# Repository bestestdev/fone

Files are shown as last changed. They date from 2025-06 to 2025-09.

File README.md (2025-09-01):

# fone

A modern take on the classic Nokia cell phone experience, built with a Raspberry Pi Pico 2 running MicroPython. This project combines the simplicity and reliability of old-school Nokia phones with quality-of-life improvements for modern usability.

## Overview

**fone** is a DIY cellular phone that captures the essence of classic Nokia devices while incorporating modern components and conveniences. The device features a minimalist design focused on essential communication functions: calls, SMS, and basic navigation, all powered by MicroPython for easy customization and development.

## Hardware Components

### Core Processing
- **Raspberry Pi Pico 2** - Main microcontroller running MicroPython
- **W25Q128 SPI Flash** - 16MB flash storage for contacts, messages, and system data

### Cellular Communication
- **SIM7600G Module** - 4G/LTE cellular connectivity with GPS
- Connected via UART (TX/RX) to Pico 2

### Power Management
- **3700mAh Lithium Battery** - Long-lasting power source
- **TP4056 Charging Module** - Safe battery charging via USB-C
- **MT3608 Boost Converter** - Boost LiPo battery to 5v for use by the SIM module and Pico

### Audio System
- **MAX98357A I2S Amplifier** - Digital audio amplification
- **1W 8Ω Speaker** - Clear audio output for calls and notifications
- **GY-MAX4466 Electret Microphone** - Voice input with AGC
- **ADS1115 ADC** - High-resolution analog-to-digital conversion for microphone

### Display & Input
- **2.42" OLED Display (SSD1309)** - monochrome, 128x64 resolution, SPI interface, low power consumption
- **ANO Directional Navigation and Scroll Wheel Rotary Encoder** - Navigation, selection, scroll, and menu control
- **3V Coin Vibration Motor** - Haptic feedback and notifications

## Features

### Core Functionality
- **Voice Calls** - Make and receive phone calls with clear audio
- **SMS Messaging** - Send and receive text messages
- **Contact Management** - Store and organize phone contacts
- **Call History** - Track incoming, outgoing, and missed calls

### Enhanced User Experience
- **Improved Text Input** - Modern T9-style predictive text with encoder navigation
- **Menu Navigation** - Intuitive interface designed for encoder and directional button control
- **Scroll Wheel Support** - Rotary encoder provides smooth scrolling through lists and menus
- **Low Power Operation** - E-paper display and efficient power management
- **Haptic Feedback** - Vibration for notifications and user interactions

### Additional Features
- **GPS Location (Stretch Goal)** - Built-in positioning via SIM7600G
- **Battery Monitoring** - Real-time battery level and charging status
- **Silent/Vibrate Modes** - Customizable notification preferences
- **Basic Games** - Classic Nokia-style entertainment (Snake, etc.)

## Technical Specifications

### Connectivity
- **Cellular**: 4G LTE via SIM7600G
- **GPS (Stretch Goal)**: Built-in GNSS receiver
- **Storage**: 16MB SPI flash memory (W25Q128)

### Power
- **Battery Life**: All-day usage with 3700mAh capacity
- **Charging**: USB charging via TP4056 module
- **Standby**: Ultra-low power consumption with e-paper display

### Interface
- **Display**: 2.42" monochrome OLED (128x64px)
- **Input**: ANO rotary encoder with directional navigation buttons
- **Audio**: Full-duplex voice communication
- **Feedback**: Vibration motor for alerts

## Software Architecture

- **Platform**: MicroPython on Raspberry Pi Pico 2
- **Modular Design**: Separate modules for cellular, audio, display, and input handling
- **Event-Driven**: Efficient power management through interrupt-based operation
- **Extensible**: Easy to add new features and customize behavior

## Wiring Guide

### SIM7600G to Raspberry Pi Pico 2

The SIM7600G module connects via UART and requires the following connections:

| SIM7600G Pin | Description | Connection | Notes |
|---|---|---|---|
| **V** | VCC | **5V from MT3608** | Requires stable 5V (up to 2A) |
| **G** | Ground | **Battery -** | Battery ground |
| **G** | Ground | **Pico GND** (Pin 38) | Shared ground with Pico |
| **T** | TX (Module transmit) | **GP1** (Pin 2) | UART0 RX |
| **R** | RX (Module receive) | **GP0** (Pin 1) | UART0 TX |
| **K** | Power Key | **GP2** (Pin 4) | GPIO for power control |
| **S** | Status | **GP3** (Pin 5) | GPIO for status monitoring |

#### Key Points:
- **Power**: SIM7600G requires 5V via MT3608 boost converter for proper RF operation
- **Current Draw**: Module can draw up to 2A during transmission bursts
- **UART**: Cross-connect TX/RX (module TX → Pico RX, module RX → Pico TX)
- **Power Key**: Pull HIGH briefly to turn module on/off
- **Status**: Monitor this pin to check if module is powered and ready
- **Dual Ground**: Connect both ground pins for stable operation

### ANO Directional Navigation and Scroll Wheel Rotary Encoder

The primary input is an ANO directional navigation and scroll wheel rotary encoder, providing directional control, rotary scroll input, and a center-press button.

| Encoder Pin | Description | Connection | Notes |
|---|---|---|---|
| **ENCA** | Encoder A Pin | **GP17** (Pin 22) | Rotary encoder quadrature A |
| **ENCB** | Encoder B Pin | **GP22** (Pin 29) | Rotary encoder quadrature B |
| **SW1** | Center Button | **GP6** (Pin 9) | Digital input |
| **SW2** | Down Button | **GP5** (Pin 7) | Digital input |
| **SW3** | Right Button | **GP4** (Pin 6) | Digital input |
| **SW4** | Up Button | **GP19** (Pin 25) | Digital input |
| **SW5** | Left Button | **GP18** (Pin 24) | Digital input |
| **COM** | Common | **GND** (Pin 38) | Common ground for all switches |

#### Key Points:
- **Rotary Encoder**: ENCA/ENCB provide quadrature signals for scroll wheel functionality
- **Digital Buttons**: All switch pins (SW1-SW5) are simple digital inputs
- **Wiring**: Connect the COM pin to GND and configure each GPIO pin as an input with an internal pull-up resistor
- **Active Low**: Button presses and encoder transitions pull pins to ground (LOW)
- **Quadrature Decoding**: Software tracks encoder A/B state changes to determine rotation direction and steps

### Dual Analog Joysticks via ADS1115 ADC

> **Note:** This component has been deprecated and replaced by the ANO Directional Navigation and Scroll Wheel Rotary Encoder.

The phone uses two analog joysticks for navigation and input, connected through an ADS1115 16-bit ADC for full 4-channel analog precision.

**ADS1115 ADC Module:**

| ADS1115 Pin | Description | Connection | Notes |
|---|---|---|---|
| **VDD** | Power | **5V** (Pin 40 - VBUS) | Module power supply |
| **GND** | Ground | **GND** (Pin 38) | Common ground |
| **SCL** | I2C Clock | **GP21** (Pin 27) | I2C0 SCL |
| **SDA** | I2C Data | **GP20** (Pin 26) | I2C0 SDA |
| **ADDR** | Address | **GND** | Sets I2C address to 0x48 |

**Left Joystick (mounted upside down):**

| Joystick Pin | Description | Connection | Notes |
|---|---|---|---|
| **VCC** | Power | **5V** (Pin 40 - VBUS) | Joystick power supply |
| **GND** | Ground | **GND** (Pin 38) | Common ground |
| **VRX** | X-axis analog | **ADS1115 AIN0** | Left joystick X |
| **VRY** | Y-axis analog | **ADS1115 AIN1** | Left joystick Y (inverted) |
| **SW** | Switch button | **GP19** (Pin 25) | Digital input with pull-up |

**Right Joystick:**

| Joystick Pin | Description | Connection | Notes |
|---|---|---|---|
| **VCC** | Power | **5V** (Pin 40 - VBUS) | Joystick power supply |
| **GND** | Ground | **GND** (Pin 38) | Common ground |
| **VRX** | X-axis analog | **ADS1115 AIN2** | Right joystick X |
| **VRY** | Y-axis analog | **ADS1115 AIN3** | Right joystick Y |
| **SW** | Switch button | **GP18** (Pin 24) | Digital input with pull-up |

#### Key Points:
- **Full Analog Control**: ADS1115 provides 4 channels of 16-bit ADC precision
- **I2C Address**: 0x48 (ADDR pin to GND), can be changed for multiple modules
- **Left Joystick**: Mounted upside down, so Y-axis values are inverted in software
- **ADC Resolution**: 16-bit (±32767) with ±4.096V input range matches 5V joysticks
- **Switches**: Active low with internal pull-up resistors on Pico pins (3.3V logic)
- **Update Rate**: ~128 SPS (samples per second) for smooth control

### 3V Vibration Motor

The vibration motor provides haptic feedback for notifications and user interactions.

#### Option 1: Direct GPIO Control (Recommended to try first)

**For Low Current Motors (< 40mA):**

| Motor Pin | Description | Connection | Notes |
|---|---|---|---|
| **+** | Positive | **GP16** (Pin 21) | Direct PWM control |
| **-** | Negative | **GND** (Pin 38) | Direct ground connection |

#### Option 2: Transistor-Protected Control

**For Higher Current Motors (> 40mA) or if direct control fails:**

| Motor Pin | Description | Connection | Notes |
|---|---|---|---|
| **+** | Positive | **GP16** (Pin 21) via NPN Transistor | PWM-controlled output |
| **-** | Negative | **GND** (Pin 38) | Direct ground connection |

**Transistor Circuit (NPN - 2N2222 or similar):**

| Transistor Pin | Description | Connection | Notes |
|---|---|---|---|
| **Base** | Control | **GP16** (Pin 21) via 1kΩ resistor | PWM signal from Pico |
| **Collector** | High side | **Motor +** | Connects to motor positive |
| **Emitter** | Ground | **GND** (Pin 38) | Common ground |

#### Key Points:
- **Motor Specs**: 3V, 12000 RPM, small coin-type vibration motor
- **Current Draw**: Small motors (17-35mA) can connect directly, larger motors (60-105mA) need transistor
- **Pico GPIO Limits**: ~16mA safe, ~50mA maximum per pin
- **Try Direct First**: Start with Option 1 - if motor doesn't work well or Pico gets warm, use Option 2
- **Flyback Diode**: Optional 1N4001 diode across motor (cathode to +, anode to -) for back-EMF protection
- **Control**: PWM control via GP16 allows variable vibration intensity
- **Frequency**: Typical vibration patterns: short bursts (100-300ms) for notifications

### 2.42" OLED Display (SSD1309)

The 2.42" monochrome OLED display provides the main user interface with a 128x64 resolution using SPI communication.

**Display Module Connections:**

| Display Pin | Description | Connection | Notes |
|---|---|---|---|
| **VCC** | Power | **3V3** (Pin 36) | 3.3V power supply |
| **GND** | Ground | **GND** (Pin 38) | Common ground |
| **CLK** | SPI Clock | **GP10** (Pin 14) | SPI1 SCK |
| **DIN** | SPI Data In | **GP11** (Pin 15) | SPI1 MOSI (TX) |
| **CS** | Chip Select | **GP9** (Pin 12) | SPI chip select (active low) |
| **DC** | Data/Command | **GP12** (Pin 16) | Command mode control |
| **RST** | Reset | **GP13** (Pin 17) | Hardware reset (active low) |

#### Key Points:
- **SPI Interface**: Uses SPI1 on Pico 2 for communication
- **Monochrome Display**: Black and white output with high contrast
- **Resolution**: 128x64 pixels provides clear text and simple graphics
- **Fast Updates**: ~10ms refresh time for full screen updates
- **Low Power**: Efficient power consumption (perfect for phone standby)
- **Rotation Support**: Software rotation for portrait or landscape orientation
- **Viewing Angle**: Wide viewing angle (>160°) for clear visibility
- **Compact Size**: 2.42" diagonal with minimal bezel

### W25Q128 SPI Flash Memory Module

The W25Q128 provides 16MB (128Mbit) of non-volatile storage for contacts, messages, and system data, connected via SPI interface. This flash memory offers faster access times and lower power consumption compared to SD cards.

**W25Q128 Module Connections:**

| W25Q128 Pin | Description | Connection | Notes |
|---|---|---|---|
| **VCC** | Power | **3V3** (Pin 36) | 3.3V power supply |
| **GND** | Ground | **GND** (Pin 38) | Common ground |
| **DC** | SPI Data Out (MISO) | **GP8** (Pin 11) | SPI1 MISO (RX) |
| **D1** | SPI Data In (MOSI) | **GP11** (Pin 15) | SPI1 MOSI (TX) - **Shared with display** |
| **SLK** | SPI Clock | **GP10** (Pin 14) | SPI1 SCK - **Shared with display** |
| **CS** | Chip Select | **GP7** (Pin 10) | SPI chip select (active low) |

#### Key Points:
- **Shared SPI Bus**: Uses SPI1 shared with the e-paper display (SLK, D0 pins)
- **Separate MISO**: Flash memory has its own MISO line (D1/GP8) since display is write-only
- **Unique CS**: Each device has its own chip select (Flash: GP7, Display: GP9)
- **Power**: 3.3V operation, low power consumption (4mA active, <1µA standby)
- **Storage**: 16MB of flash memory with 100,000+ erase/program cycles
- **Performance**: Up to 104MHz SPI clock, much faster than SD card access
- **File System**: Can use LittleFS or FAT filesystem via MicroPython's VFS

### MAX98357A I2S Amplifier and Speaker

The MAX98357A is a digital I2S audio amplifier used to drive the speaker for calls, notifications, and other audio feedback.

**MAX98357A Module Connections:**

| MAX98357A Pin | Description | Connection | Notes |
|---|---|---|---|
| **Vin** | Power In | **5V** (Pin 40 - VBUS) | 3-5.5V input range |
| **GND** | Ground | **GND** (Pin 38) | Common ground |
| **DIN** | Data In | **GP20** (Pin 26) | I2S Serial Data |
| **BCLK** | Bit Clock | **GP14** (Pin 19) | I2S Bit Clock |
| **LRC** | Left-Right Clock | **GP15** (Pin 20) | I2S Word Select |
| **SD** | Shutdown | **GP21** (Pin 27) | Active-low shutdown control |
| **GAIN** | Gain Select | *(unconnected)* | Default 9dB gain. Connect to GND for 3dB, VCC for 15dB. |

**Speaker Connection:**

| Component | Connection |
|---|---|
| **Speaker +** | **MAX98357A Left/Right +** |
| **Speaker -** | **MAX98357A Left/Right -** |

#### Key Points:
- **I2S Audio**: Digital audio provides clear, noise-free sound.
- **Power**: Connected to 5V for maximum speaker volume.
- **Shutdown Pin**: GP21 controls the amplifier's shutdown mode to conserve power.
- **Mono Output**: Although the module has L/R outputs, it's a mono amplifier. Connect speaker to either pair.
- **Gain Control**: The `GAIN` pin can be used to adjust the amplification level if needed. Default (unconnected) is 9dB.

### GY-MAX4466 Electret Microphone

The GY-MAX4466 microphone module with automatic gain control (AGC) is used for voice input. It's connected directly to one of the Pico's ADC pins.

**Microphone Module Connections:**

| Microphone Pin | Description | Connection | Notes |
|---|---|---|---|
| **VCC** | Power | **3V3** (Pin 36) | 2.4-5.5V input range |
| **GND** | Ground | **GND** (Pin 38) | Common ground |
| **OUT** | Analog Out | **GP28** (Pin 34) | Connects to ADC2 |

#### Key Points:
- **Direct ADC Connection**: Simplifies wiring and reduces component count.
- **Analog Pin**: Uses `GP28`, one of the Pico's three dedicated ADC pins.
- **Power**: Runs on 3.3V power provided by the Pico.
- **AGC**: The MAX4466's automatic gain control adjusts for varying sound levels.

### Battery Level Monitoring

To monitor the battery level, a voltage divider is used to scale the battery's voltage (3.0V-4.2V) down to a range the Pico's ADC can safely read (0-3.3V). The reading is taken on the now-available ADC pin.

**Voltage Divider Circuit:**

| Component | Connection | Notes |
|---|---|---|
| **Battery +** | Resistor 1 (R1) - e.g., 100kΩ | Connects to the positive battery terminal |
| **R1 + R2** | **GP26** (Pin 31) & Resistor 2 (R2) | Center point connects to Pico's ADC pin |
| **R2** | **GND** (Pin 38) | Connects to ground |

*A 1:1 ratio (e.g., two 100kΩ resistors) is simple and effective.*

**Pin Connection:**

| Description | Connection | Notes |
|---|---|---|
| **Voltage Sense** | **GP26** (Pin 31) | ADC capable pin (ADC0) |

#### Key Points:
- **Voltage Divider**: Essential to prevent damage to the Pico's ADC.
- **Resistor Choice**: Using identical resistors (e.g., 100kΩ) creates a simple 1:2 divider. The actual voltage is `2 * adc_voltage`.
- **ADC Reading**: The software must read the analog value from `GP26` and multiply it by the divider ratio to calculate the true battery voltage.

*[Development in progress - setup instructions coming soon]*

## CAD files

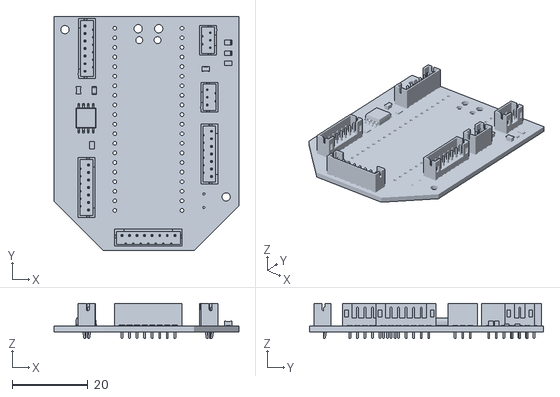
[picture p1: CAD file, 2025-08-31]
stls/fone-pcb.stl
49.0 x 62.0 x 9.40

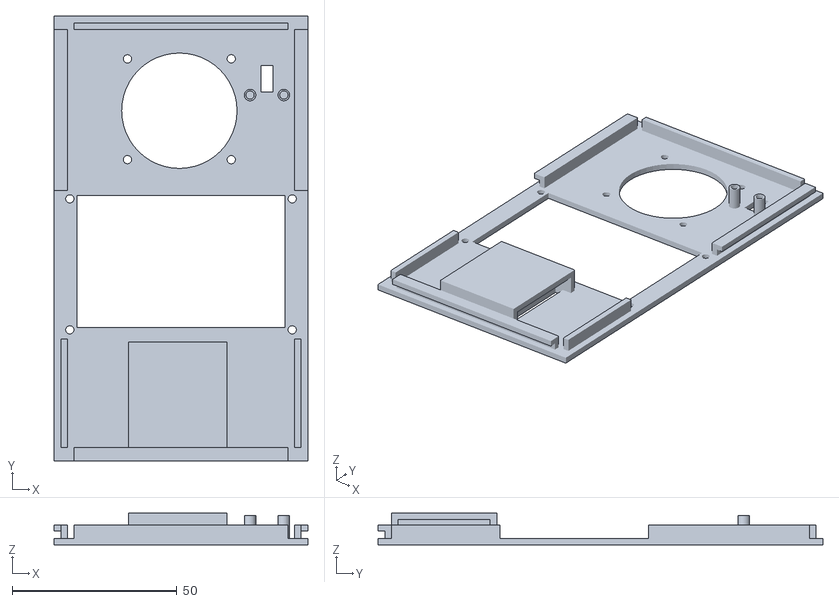
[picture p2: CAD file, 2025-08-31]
stls/fone 0.5 top.stl
77.0 x 135.1 x 9.70

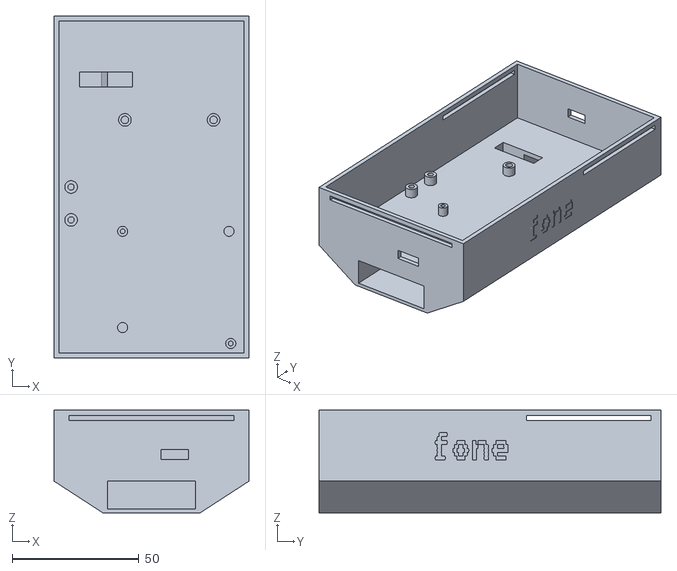
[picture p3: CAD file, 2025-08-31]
stls/fone 0.5 bottom.stl
77.0 x 135.0 x 40.5

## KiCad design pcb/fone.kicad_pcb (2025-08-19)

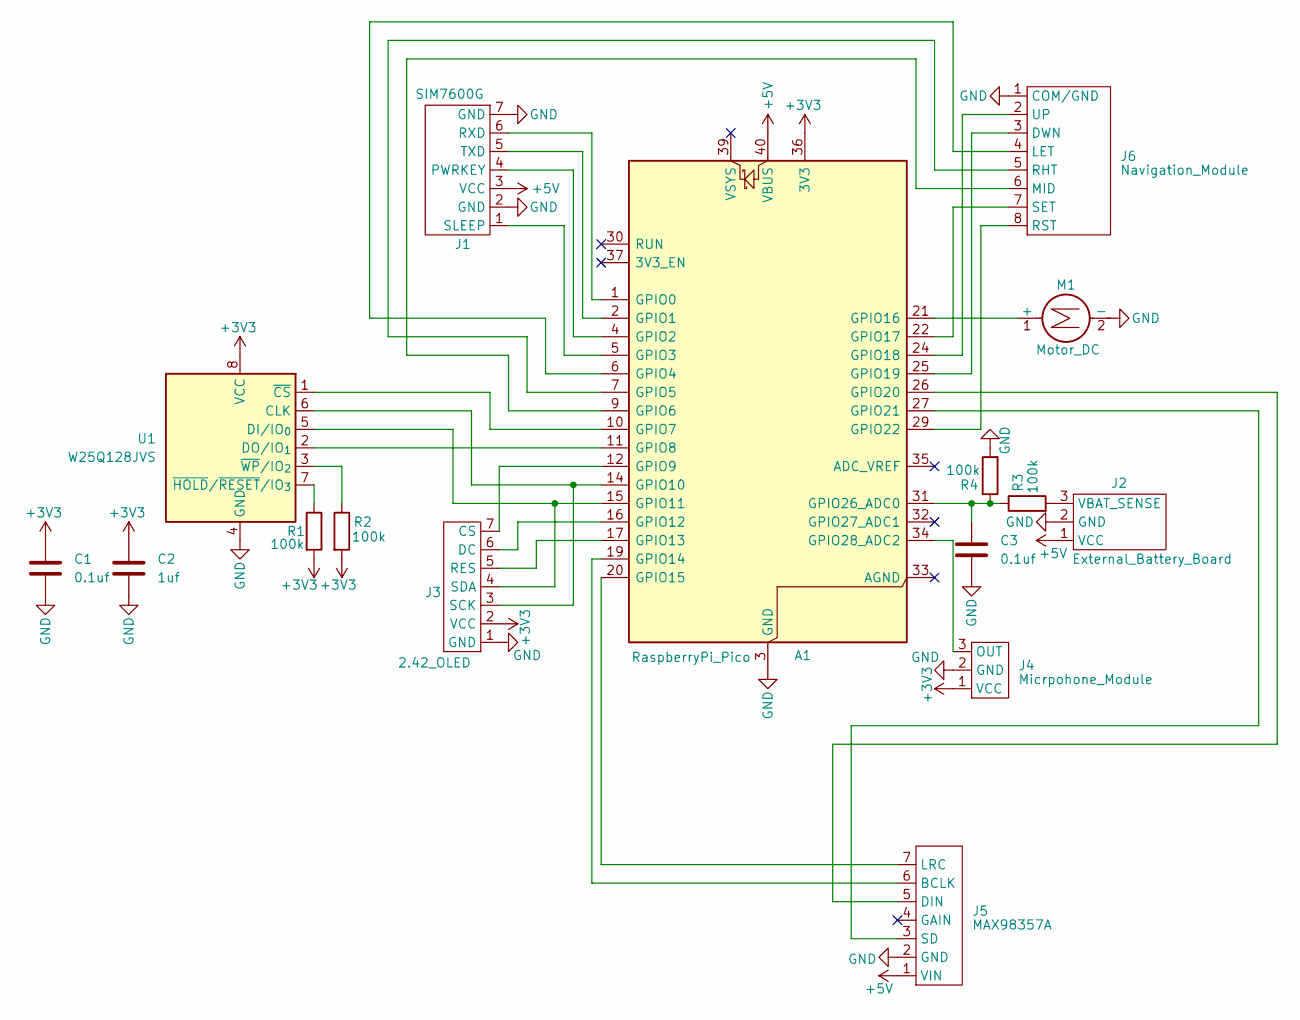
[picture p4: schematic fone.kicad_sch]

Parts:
A1: RaspberryPi_Pico; RaspberryPi_Pico_Common_Unspecified
C1, C3: 0.1uf; C_0805_2012Metric_Pad1.18x1.45mm_HandSolder
C2: 1uf; C_0805_2012Metric_Pad1.18x1.45mm_HandSolder
J1: SIM7600G; JST_PH_B7B-PH-K_1x07_P2.00mm_Vertical
J2: External_Battery_Board; JST_PH_B3B-PH-K_1x03_P2.00mm_Vertical
J3: 2.42_OLED; JST_PH_B7B-PH-K_1x07_P2.00mm_Vertical
J4: Micrpohone_Module; JST_PH_B3B-PH-K_1x03_P2.00mm_Vertical
J5: MAX98357A; JST_PH_B7B-PH-K_1x07_P2.00mm_Vertical
J6: Navigation_Module; JST_PH_B8B-PH-K_1x08_P2.00mm_Vertical
M1: Motor_DC; SolderWire-2sqmm_1x02_P7.8mm_D2mm_OD3.9mm
R1, R2, R3, R4: 100k; R_0805_2012Metric_Pad1.20x1.40mm_HandSolder
U1: W25Q128JVS; SOIC-8_5.3x5.3mm_P1.27mm

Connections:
+3V3: A1.36 (3V3), C1.1, C2.1, J3.2 (VCC), J4.1 (VCC), R1.2, R2.2, U1.8 (VCC)
+5V: A1.40 (VBUS), J1.3 (VCC), J2.1 (VCC), J5.1 (VIN)
GND: A1.3 (GND), A1.8 (GND), A1.13 (GND), A1.18 (GND), A1.23 (GND), A1.28 (GND), A1.38 (GND), C1.2, C2.2, C3.2, J1.2 (GND), J1.7 (GND), J2.2 (GND), J3.1 (GND), J4.2 (GND), J5.2 (GND), J6.1 (COM/GND), M1.2 (-), R4.2, U1.4 (GND)
unnamed: A1.1 (GPIO0), J1.6 (RXD)
unnamed: A1.2 (GPIO1), J1.5 (TXD)
unnamed: A1.4 (GPIO2), J1.4 (PWRKEY)
unnamed: A1.5 (GPIO3), J1.1 (SLEEP)
unnamed: A1.6 (GPIO4), J6.4 (LET)
unnamed: A1.7 (GPIO5), J6.5 (RHT)
unnamed: A1.9 (GPIO6), J6.6 (MID)
unnamed: A1.10 (GPIO7), U1.1 (~CS)
unnamed: A1.11 (GPIO8), U1.2 (DO/IO_{1})
unnamed: A1.12 (GPIO9), J3.7 (CS)
unnamed: A1.14 (GPIO10), J3.3 (SCK), U1.6 (CLK)
unnamed: A1.15 (GPIO11), J3.4 (SDA), U1.5 (DI/IO_{0})
unnamed: A1.16 (GPIO12), J3.6 (DC)
unnamed: A1.17 (GPIO13), J3.5 (RES)
unnamed: A1.19 (GPIO14), J5.6 (BCLK)
unnamed: A1.20 (GPIO15), J5.7 (LRC)
unnamed: A1.21 (GPIO16), M1.1 (+)
unnamed: A1.22 (GPIO17), J6.7 (SET)
unnamed: A1.24 (GPIO18), J6.2 (UP)
unnamed: A1.25 (GPIO19), J6.3 (DWN)
unnamed: A1.26 (GPIO20), J5.5 (DIN)
unnamed: A1.27 (GPIO21), J5.3 (SD)
unnamed: A1.29 (GPIO22), J6.8 (RST)
unnamed: A1.31 (GPIO26_ADC0), C3.1, R3.1, R4.1
unnamed: A1.34 (GPIO28_ADC2), J4.3 (OUT)
unnamed: J2.3 (VBAT_SENSE), R3.2
unnamed: R1.1, U1.7 (~HOLD/~RESET/IO_{3})
unnamed: R2.1, U1.3 (~WP/IO_{2})

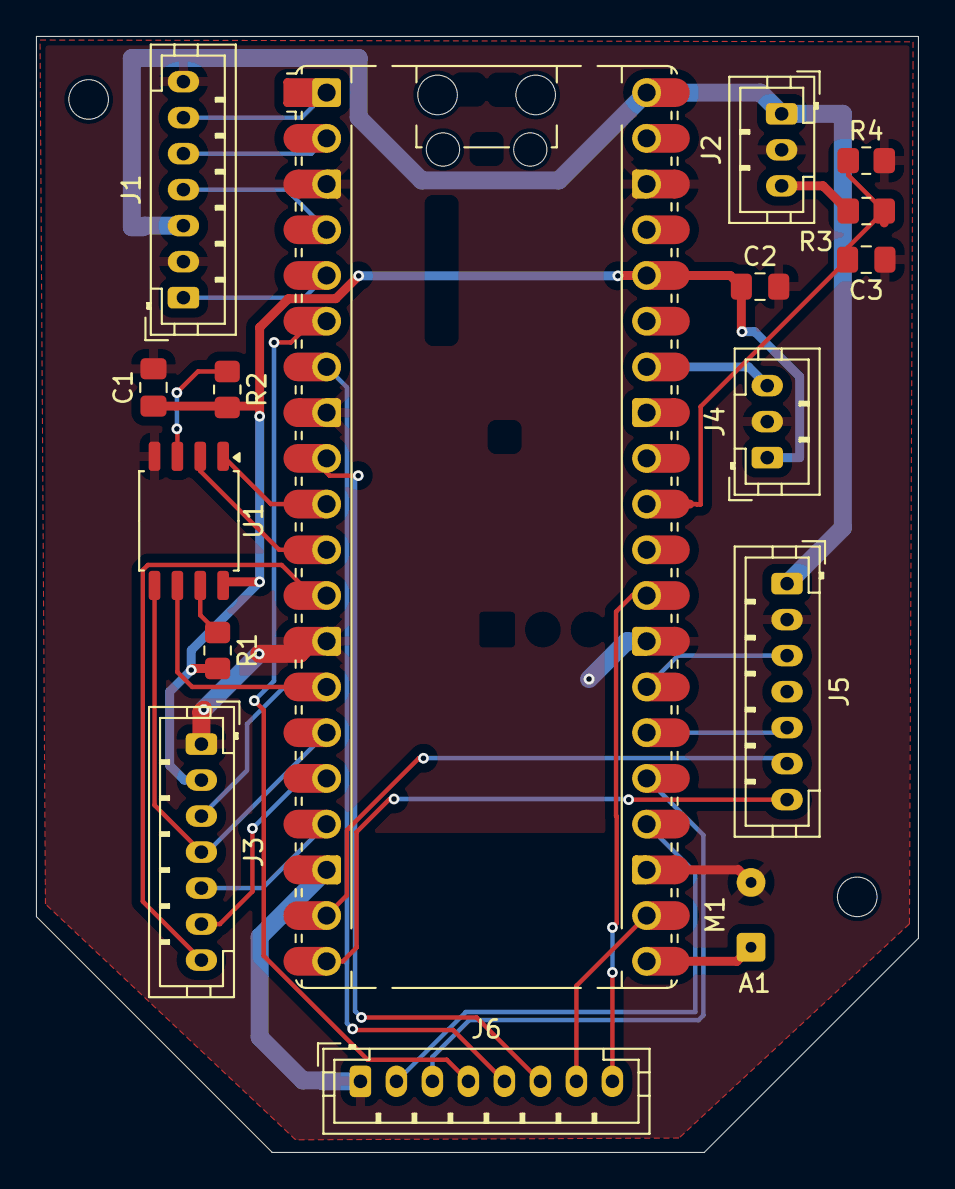
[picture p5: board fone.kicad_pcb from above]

Board: 2 copper layers, 49.0 x 62.0 mm, 18 parts (0 on the bottom side), 31 nets.

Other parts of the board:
HOLE1, HOLE2: MountingHole_2.2mm_M2

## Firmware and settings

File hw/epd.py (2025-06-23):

# *****************************************************************************
# * | File        :	  Pico_ePaper-4.2-B-Rotated.py
# * | Author      :   Enhanced with rotation support
# * | Function    :   Electronic paper driver with rotation capabilities
# * | Info        :
# *----------------
# * | This version:   V1.1 - Added rotation support
# * | Date        :   2023-06-23
# # | Info        :   Enhanced python demo with rotation
# *
# * Features:
# * - Support for 0°, 90°, 180°, and 270° rotation
# * - Automatic buffer handling for different orientations
# * - Maintains compatibility with original driver
# * - Efficient memory usage with proper buffer alignment
# * - Portrait and landscape modes
# *
# * Usage:
# * - Initialize with rotation: epd = EPD_4in2_B(rotation=90)
# * - Change rotation dynamically: epd.set_rotation(180)
# * - Get current dimensions: width, height = epd.get_effective_dimensions()
# *
# * Note: When using 90° or 270° rotation, width and height are swapped
# -----------------------------------------------------------------------------

from machine import Pin, SPI
import framebuf
import utime

# Display resolution
EPD_WIDTH       = 400
EPD_HEIGHT      = 300

# pins
SPI_SCK = Pin(10)    # SPI1 SCK - GP10 (Pin 14)
SPI_MOSI = Pin(11)   # SPI1 MOSI - GP11 (Pin 15) 
SPI_CS = Pin(9)      # Chip Select - GP9 (Pin 12)
SPI_DC = Pin(12)     # Data/Command - GP12 (Pin 16)
SPI_RST = Pin(13)    # Reset - GP13 (Pin 17)
SPI_BUSY = Pin(27)   # Busy status - GP27 (Pin 32)


class EPD_4in2_B:
    def __init__(self, rotation=0):
        """
        Initialize EPD with optional rotation
        rotation: 0, 90, 180, or 270 degrees
        """
        self.reset_pin = Pin(SPI_RST, Pin.OUT)
        self.busy_pin = Pin(SPI_BUSY, Pin.IN, Pin.PULL_UP)
        self.cs_pin = Pin(SPI_CS, Pin.OUT)
        self.sck_pin = 1
        self.din_pin = 1
        
        # Hardware dimensions (always 400x300)
        self.hw_width = EPD_WIDTH
        self.hw_height = EPD_HEIGHT
        
        # Set rotation and calculate effective dimensions
        # Ensure rotation is an integer
        try:
            rotation = int(rotation)
        except (ValueError, TypeError):
            rotation = 0  # Default to 0 if conversion fails
            
        self.rotation = rotation % 360
        
        # Check if rotation is one of the valid values
        valid_rotations = [0, 90, 180, 270]
        if self.rotation not in valid_rotations:
            # Round to nearest valid rotation instead of raising an error
            closest = min(valid_rotations, key=lambda x: abs(x - self.rotation))
            self.rotation = closest
        
        # Effective dimensions after rotation
        if self.rotation % 180 == 0:
            self.width = self.hw_width   # 400
            self.height = self.hw_height # 300
        else:
            self.width = self.hw_height  # 300 
            self.height = self.hw_width  # 400
        
        self.flag = 0
        
        self.spi = SPI(1,baudrate=4000_000,sck=Pin(SPI_SCK),mosi=Pin(SPI_MOSI))
        self.dc_pin = Pin(SPI_DC, Pin.OUT)
        
        # Create working framebuffers based on effective dimensions
        # Calculate buffer size - ensure it's a multiple of 8 bytes for proper alignment
        stride = (self.width + 7) // 8  # Bytes per row, rounded up
        buffer_size = stride * self.height
        
        try:
            # Create bytearrays
            self.buffer_black = bytearray(buffer_size)
            self.buffer_red = bytearray(buffer_size)
            
            # Create framebuffers - use MONO_HLSB format (1 bit per pixel, horizontal)
            try:
                self.imageblack = framebuf.FrameBuffer(self.buffer_black, self.width, self.height, framebuf.MONO_HLSB)
            except Exception:
                # Try alternate constructor format
                self.imageblack = framebuf.FrameBuffer(self.buffer_black, self.width, self.height, framebuf.MONO_HLSB, stride)
                
            try:
                self.imagered = framebuf.FrameBuffer(self.buffer_red, self.width, self.height, framebuf.MONO_HLSB)
            except Exception:
                # Try alternate constructor format
                self.imagered = framebuf.FrameBuffer(self.buffer_red, self.width, self.height, framebuf.MONO_HLSB, stride)
                
        except Exception as e:
            import sys
            sys.print_exception(e)
            raise ValueError(f"Failed to allocate memory for display buffers: {e}")
        
        # Hardware buffers for actual display (always 400x300)
        hw_stride = (self.hw_width + 7) // 8  # Bytes per row, rounded up
        hw_buffer_size = hw_stride * self.hw_height
        
        try:
            self.hw_buffer_black = bytearray(hw_buffer_size)
            self.hw_buffer_red = bytearray(hw_buffer_size)
        except Exception as e:
            import sys
            sys.print_exception(e)
            raise ValueError(f"Failed to allocate memory for hardware buffers: {e}")
        
        try:
            self.EPD_4IN2B_Init()
            self.EPD_4IN2B_Clear()
            utime.sleep_ms(500)
        except Exception as e:
            import sys
            sys.print_exception(e)
            raise ValueError(f"Failed to initialize display: {e}")
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

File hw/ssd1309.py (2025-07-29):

from machine import Pin, SPI
import framebuf
import time

# SSD1309 2.42" OLED Display Constants
OLED_WIDTH = 128
OLED_HEIGHT = 64

class SSD1309:
    def __init__(self, spi, dc, cs, rst, width=OLED_WIDTH, height=OLED_HEIGHT, rotation=0):
        """
        Initialize the SSD1309 OLED display with SPI interface
        
        Args:
            spi: SPI interface
            dc: Data/Command pin
            cs: Chip Select pin
            rst: Reset pin
            width: Display width in pixels
            height: Display height in pixels
            rotation: Display rotation (0, 90, 180, or 270 degrees)
        """
        self.spi = spi
        self.dc = dc
        self.cs = cs
        self.rst = rst
        self.width = width
        self.height = height
        self.buffer = bytearray(self.width * self.height // 8)
        self.framebuf = framebuf.FrameBuffer(self.buffer, self.width, self.height, framebuf.MONO_VLSB)
        
        # Set rotation
        self.set_rotation(rotation)
        
        # Initialize display
        self.reset()
        self.init_display()
        
    def reset(self):
        """Reset the display"""
        self.rst.value(1)
        time.sleep(0.1)
        self.rst.value(0)
        time.sleep(0.1)
        self.rst.value(1)
        time.sleep(0.1)
        
    def set_rotation(self, rotation):
        """Set display rotation (0, 90, 180, or 270 degrees)"""
        self.rotation = rotation % 360
        
        # Validate rotation
        if self.rotation not in [0, 90, 180, 270]:
            self.rotation = 0  # Default to no rotation
            
        # Update effective dimensions based on rotation
        if self.rotation in [0, 180]:
            self.effective_width = self.width
            self.effective_height = self.height
        else:
            self.effective_width = self.height
            self.effective_height = self.width
            
    def get_effective_dimensions(self):
        """Return the effective drawing dimensions based on rotation"""
        return self.effective_width, self.effective_height
            
    def init_display(self):
        """Initialize the OLED display with required commands"""
        # Initialization commands for SSD1309
        init_commands = [
            0xAE,       # Display off
            0xD5, 0x80, # Set display clock divide ratio/oscillator frequency
            0xA8, 0x3F, # Set multiplex ratio (1/64)
            0xD3, 0x00, # Set display offset
            0x40,       # Set start line at line 0
            0x8D, 0x14, # Enable charge pump
            0x20, 0x00, # Set memory addressing mode (horizontal)
            0xA1,       # Set segment re-map (A0/A1)
            0xC8,       # Set COM output scan direction (C0/C8)
            0xDA, 0x12, # Set COM pins hardware configuration
            0x81, 0xCF, # Set contrast control
            0xD9, 0xF1, # Set pre-charge period
            0xDB, 0x40, # Set VCOMH deselect level
            0xA4,       # Display ON with RAM content
            0xA6,       # Normal display (not inverted)
            0xAF        # Display on
        ]
        
        # Send all initialization commands
        for cmd in init_commands:
            self.write_cmd(cmd)
            
        # Clear the display
        self.clear()
        
    def write_cmd(self, cmd):
        """Write a command to the display"""
        self.dc.value(0)  # Command mode
        self.cs.value(0)  # Select chip
        self.spi.write(bytearray([cmd]))
        self.cs.value(1)  # Deselect chip
        
    def write_data(self, data):
        """Write data to the display"""
        self.dc.value(1)  # Data mode
        self.cs.value(0)  # Select chip
        self.spi.write(data)
        self.cs.value(1)  # Deselect chip
        
    def clear(self):
        """Clear the display buffer"""
        self.framebuf.fill(0)
        self.show()
        
    def show(self):
        """Update the display with current buffer contents"""
        # Set column and page address for the whole display
        self.write_cmd(0x21)  # Set column address
        self.write_cmd(0)     # Start column
        self.write_cmd(127)   # End column
        
        self.write_cmd(0x22)  # Set page address
        self.write_cmd(0)     # Start page
        self.write_cmd(7)     # End page
        
        # Apply rotation if needed
        if self.rotation == 0:
            # No rotation, send buffer directly
            self.write_data(self.buffer)
        else:
            # Apply rotation to buffer
            rotated_buffer = self._get_rotated_buffer()
            self.write_data(rotated_buffer)
            
    def _get_rotated_buffer(self):
        """Get a rotated copy of the buffer based on current rotation setting"""
        if self.rotation == 0:
            return self.buffer
            
        # Create a new buffer for the rotated content
        rotated_buffer = bytearray(self.width * self.height // 8)
        temp_framebuf = framebuf.FrameBuffer(rotated_buffer, self.width, self.height, framebuf.MONO_VLSB)
        
        # Copy pixel by pixel with rotation
        for y in range(self.height):
            for x in range(self.width):
                pixel = self.framebuf.pixel(x, y)
                
                if self.rotation == 90:
                    # 90 degrees clockwise: (x,y) -> (y, width-1-x)
                    temp_framebuf.pixel(y, self.width - 1 - x, pixel)
                elif self.rotation == 180:
                    # 180 degrees: (x,y) -> (width-1-x, height-1-y)
                    temp_framebuf.pixel(self.width - 1 - x, self.height - 1 - y, pixel)
                elif self.rotation == 270:
                    # 270 degrees clockwise: (x,y) -> (height-1-y, x)
                    temp_framebuf.pixel(self.height - 1 - y, x, pixel)
                    
        return rotated_buffer
        
    def fill(self, color):
        """Fill the entire display with a color (0=black, 1=white)"""
        self.framebuf.fill(color)
        
    def pixel(self, x, y, color):
        """Set a pixel at (x,y) to the given color"""
        self.framebuf.pixel(x, y, color)
        
    def text(self, text, x, y, color):
        """Draw text at position (x,y) with the given color"""
        self.framebuf.text(text, x, y, color)
        
    def hline(self, x, y, width, color):
        """Draw a horizontal line"""
        self.framebuf.hline(x, y, width, color)
        
    def vline(self, x, y, height, color):
        """Draw a vertical line"""
        self.framebuf.vline(x, y, height, color)
        
    def line(self, x1, y1, x2, y2, color):
        """Draw a line from (x1,y1) to (x2,y2)"""
        self.framebuf.line(x1, y1, x2, y2, color)
        
    def rect(self, x, y, width, height, color):
        """Draw a rectangle outline"""
        self.framebuf.rect(x, y, width, height, color)
        
    def fill_rect(self, x, y, width, height, color):
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

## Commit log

2025-06-05 first couple tests with the SIM
2025-06-10 tried a new display. still not working.
    [epd.py, epd_4in2_test.py, image_dark.py]
2025-06-12 busted sd card test. probably wrong micropython version or something
    [epd.py]
2025-06-13 working flash mem! faster, and lower power use. don't need 32GB for this project. 8MB fine.
2025-06-13 working digital navigation module! removing analog joys because they didn't feel right with the low refresh of the e ink
    [joystick_digital_test.py]
2025-06-18 moved speaker BCLK to GP15 so we can use GP26 for a battery level indicator. Not sure if that will actually work, but need to wait to test it later
2025-07-29 swapped the EPD for an OLED display. I really wanted epaper to work. I think if I didn't expect to include SMS, I could've still gotten away with it. But wow was the display refresh slow.
    [epd_4in2_test.py, joystick_ssd1309_test.py, ssd1309.py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]
2025-08-19 added the pcb design
    [fone-B_Cu.gbl, fone-B_Mask.gbs, fone-B_Paste.gbp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]
2025-08-31 updated kicad and stls
    [fone 0.5 bottom.stl, fone 0.5 top.stl, fone-pcb.stl]
2025-09-01 working with an encoder now!
